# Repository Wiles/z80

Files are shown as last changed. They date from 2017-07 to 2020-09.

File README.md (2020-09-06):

# z80

## Purpose

Back in collage we had a real time operating systems course with targetted the Motorola 68000 CPU. It was a great course but our target platform was an emulator and not real hardware. This left a gap in my knoweldge of how things like chip selection and peripherals were handled by the hardware. Therefore I decided to design and build a barebones 8-bit computer and this is the results.

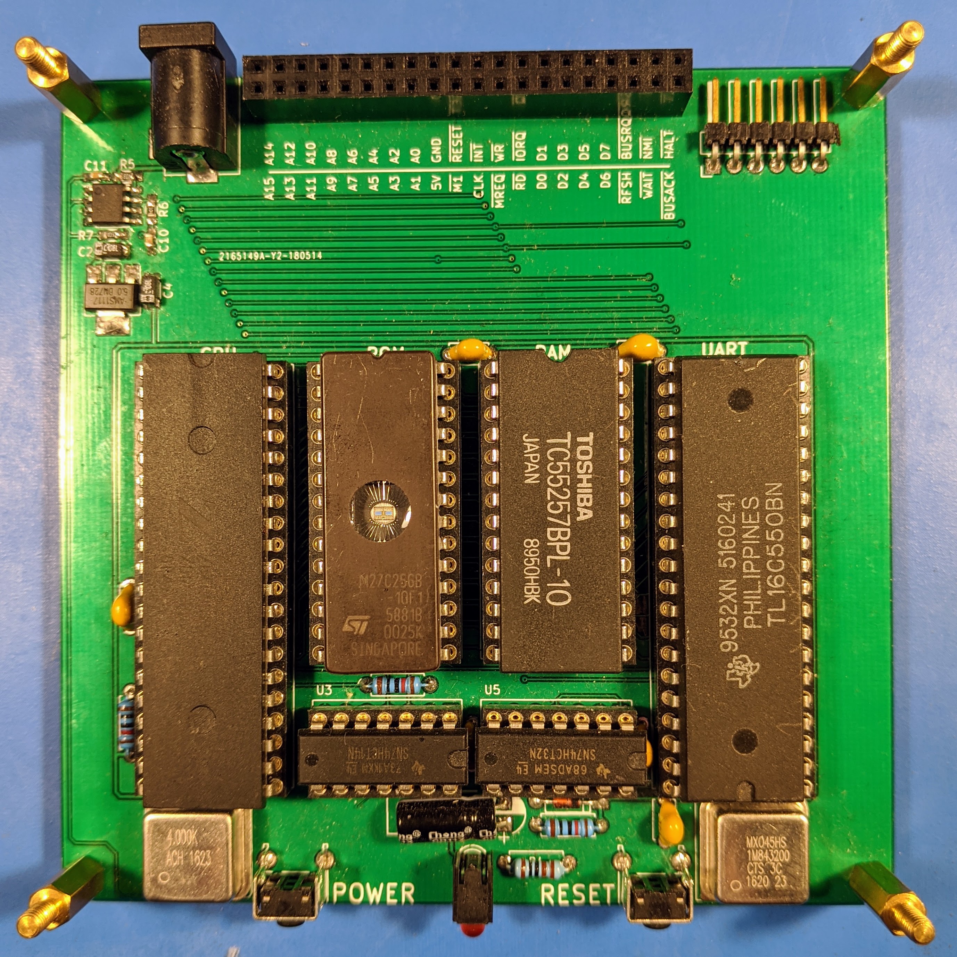
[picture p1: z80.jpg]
z80


## Memory Map

| Start | End | Description |
| --- | --- | --- |
| 0x0000 | 0x7FFF | ROM |
| 0x8000 | 0x0000 | RAM |

## IO Map

| Start | End | Description |
| --- | --- | --- |
| 0x80 | 0x87 | UART |

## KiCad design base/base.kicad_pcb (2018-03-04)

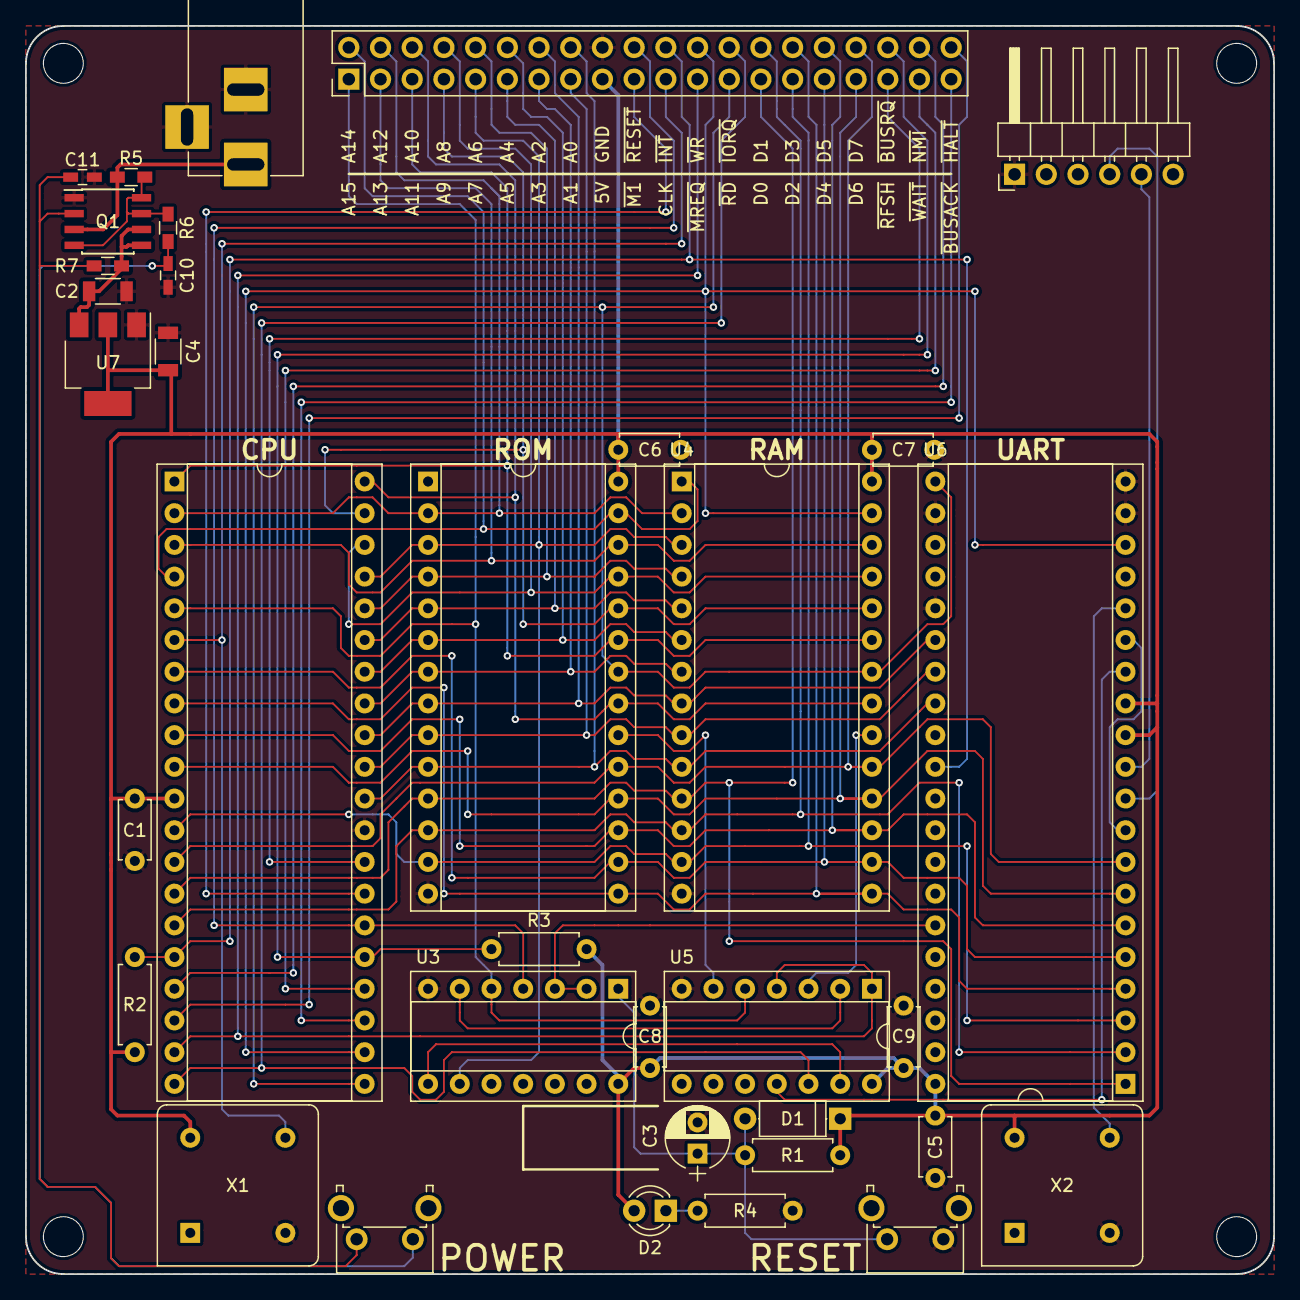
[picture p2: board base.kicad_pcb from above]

Board: 2 copper layers, 100.0 x 100.0 mm, 35 parts (0 on the bottom side), 57 nets.

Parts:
C1, C5, C6, C7, C8, C9: .1 uF; C_Disc_D4.7mm_W2.5mm_P5.00mm
C2, C4: 10 uF; C_1206
C3: 47 uF; CP_Radial_D5.0mm_P2.50mm
C10: 1 uF; C_0603_HandSoldering
C11: .1 uF; C_0603_HandSoldering
D1: 1N4148; D_A-405_P7.62mm_Horizontal
D2: LED; LED_D3.0mm
J1: FTDI; Pin_Header_Angled_1x06_Pitch2.54mm
J2: Barrel_Jack; BARREL_JACK
J3: CONN_01X40; Pin_Header_Straight_2x20_Pitch2.54mm
Q1: IRF7309IPBF; SOIC-8_3.9x4.9mm_Pitch1.27mm
R1, R2, R3: 10k; R_Axial_DIN0207_L6.3mm_D2.5mm_P7.62mm_Horizontal
R4: 1k; R_Axial_DIN0207_L6.3mm_D2.5mm_P7.62mm_Horizontal
R5, R7: 10k; R_0603_HandSoldering
R6: 100k; R_0603_HandSoldering
SW1: RESET; SW_Tactile_SPST_Angled_PTS645Vx31-2LFS
SW2: POWER; SW_Tactile_SPST_Angled_PTS645Vx31-2LFS
U1: Z80CPU; DIP-40_W15.24mm_Socket
U2: 27C256; DIP-28_W15.24mm_Socket
U3: 7404; DIP-14_W7.62mm_Socket
U4: 55257; DIP-28_W15.24mm_Socket
U5: 7432; DIP-14_W7.62mm_Socket
U6: 16550; DIP-40_W15.24mm_Socket
U7: AP1117-50; SOT-223-3Lead_TabPin2
X1: 4 MHz; Oscillator_DIP-8
X2: 1.8432 MHz; Oscillator_DIP-8

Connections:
+5V: C1.1, C4.1, C5.1, C6.1, C7.1, C8.1, C9.1, D1.1, D2.2, J3.17, R1.1, R2.2, R3.2, U1.11, U2.28, U3.14, U4.28, U5.14, U6.12, U6.13, U6.40, U7.2, X1.8, X2.8
+VDC: J2.1, Q1.3, R5.2
+VSW: C2.1, Q1.5, Q1.6, R7.1, U7.3
/A0: J3.16, U1.30, U2.10, U4.10, U6.28
/A1: J3.15, U1.31, U2.9, U4.9, U6.27
/A2: J3.14, U1.32, U2.8, U4.8, U6.26
/A3: J3.13, U1.33, U2.7, U4.7
/A4: J3.12, U1.34, U2.6, U4.6
/A5: J3.11, U1.35, U2.5, U4.5
/A6: J3.10, U1.36, U2.4, U4.4
/A7: J3.9, U1.37, U2.3, U3.9, U4.3
/A8: J3.8, U1.38, U2.25, U4.25
/A9: J3.7, U1.39, U2.24, U4.24
/A10: J3.6, U1.40, U2.21, U4.21
/A11: J3.5, U1.1, U2.23, U4.23
/A12: J3.4, U1.2, U2.2, U4.2
/A13: J3.3, U1.3, U2.26, U4.26
/A14: J3.2, U1.4, U2.27, U4.1
/A15: J3.1, U1.5, U3.5, U5.5
/D0: J3.27, U1.14, U2.11, U4.11, U6.1
/D1: J3.28, U1.15, U2.12, U4.12, U6.2
/D2: J3.29, U1.12, U2.13, U4.13, U6.3
/D3: J3.30, U1.8, U2.15, U4.15, U6.4
/D4: J3.31, U1.7, U2.16, U4.16, U6.5
/D5: J3.32, U1.9, U2.17, U4.17, U6.6
/D6: J3.33, U1.10, U2.18, U4.18, U6.7
/D7: J3.34, U1.13, U2.19, U4.19, U6.8
BUSACK: J3.39, U1.23
BUSRQ: J3.36, R3.1, U1.25
CLOCK: J3.21, U1.6, X1.5
GND: C1.2, C2.2, C3.2, C4.2, C5.2, C6.2, C7.2, C8.2, C9.2, C10.2, C11.2, J1.1, J2.2, J2.3, J3.18, Q1.1, R4.1, SW1.1, U1.29, U2.14, U3.7, U4.14, U5.7, U6.19, U6.20, U6.22, U6.25, U7.1, X1.4, X2.4
HALT: J3.40, U1.18
INT: J3.22, R2.1, U1.16, U6.30
IORQ: J3.26, U1.20, U5.12
M1: J3.19, U1.27
MREQ: J3.23, U1.19, U5.1, U5.4
NMI: J3.38, U1.17
unnamed: C3.1, D1.2, R1.2, SW1.2, U3.1
unnamed: C10.1, R6.2, SW2.1
unnamed: C11.1, Q1.2, R7.2, SW2.2
unnamed: D2.1, R4.2
unnamed: Q1.4, Q1.7, Q1.8, R5.1, R6.1
unnamed: U3.6, U5.2
unnamed: U3.8, U5.13
unnamed: U6.9, U6.15
unnamed: U6.16, X2.5
RAM_CE: U4.20, U5.3
RD: J3.25, U1.21, U2.22, U4.22, U6.21
RESET: U3.2, U3.3, U6.35
RFSH: J3.35, U1.28
ROM_CE: U2.20, U5.6
RX: J1.5, U6.11
TX: J1.4, U6.10
UART_CE: U5.11, U6.14
WAIT: J3.37, U1.24
WR: J3.24, U1.22, U4.27, U6.18
~RESET~: J3.20, U1.26, U3.4

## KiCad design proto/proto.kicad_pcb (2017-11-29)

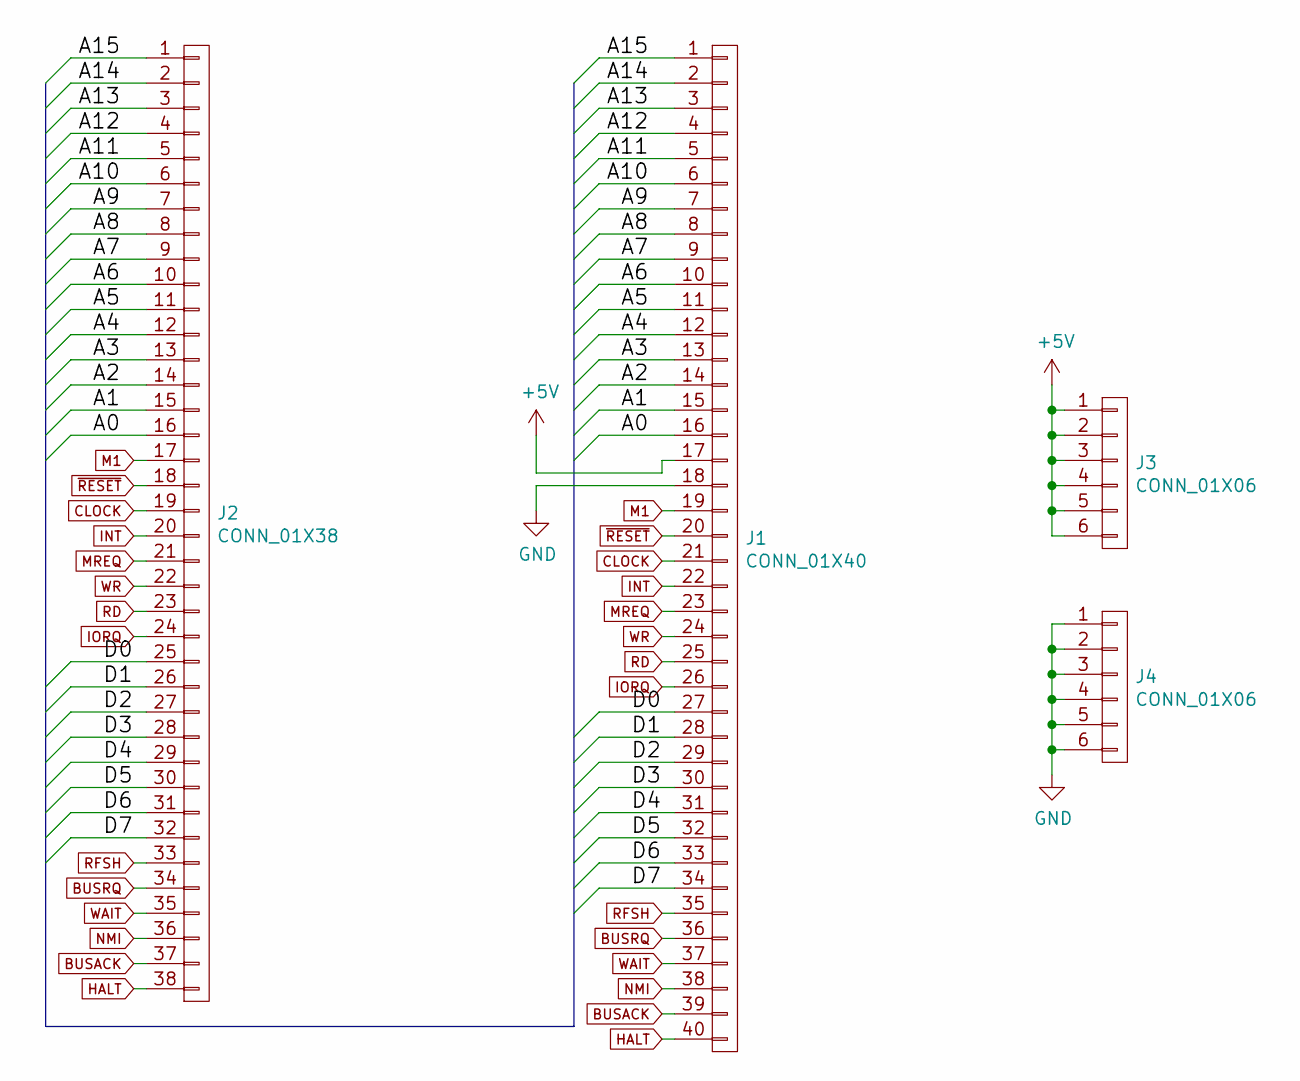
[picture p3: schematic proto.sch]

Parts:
J1: CONN_01X40; Pin_Header_Straight_2x20_Pitch2.54mm
J2: CONN_01X38; Pin_Header_Straight_1x38_Pitch2.54mm
J3, J4: CONN_01X06; Pin_Header_Straight_1x06_Pitch2.54mm

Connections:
+5V: J1.17, J3.1, J3.2, J3.3, J3.4, J3.5, J3.6
/A0: J1.16, J2.16
/A1: J1.15, J2.15
/A2: J1.14, J2.14
/A3: J1.13, J2.13
/A4: J1.12, J2.12
/A5: J1.11, J2.11
/A6: J1.10, J2.10
/A7: J1.9, J2.9
/A8: J1.8, J2.8
/A9: J1.7, J2.7
/A10: J1.6, J2.6
/A11: J1.5, J2.5
/A12: J1.4, J2.4
/A13: J1.3, J2.3
/A14: J1.2, J2.2
/A15: J1.1, J2.1
/D0: J1.27, J2.25
/D1: J1.28, J2.26
/D2: J1.29, J2.27
/D3: J1.30, J2.28
/D4: J1.31, J2.29
/D5: J1.32, J2.30
/D6: J1.33, J2.31
/D7: J1.34, J2.32
BUSACK: J1.39, J2.37
BUSRQ: J1.36, J2.34
CLOCK: J1.21, J2.19
GND: J1.18, J4.1, J4.2, J4.3, J4.4, J4.5, J4.6
HALT: J1.40, J2.38
INT: J1.22, J2.20
IORQ: J1.26, J2.24
M1: J1.19, J2.17
MREQ: J1.23, J2.21
NMI: J1.38, J2.36
RD: J1.25, J2.23
RFSH: J1.35, J2.33
WAIT: J1.37, J2.35
WR: J1.24, J2.22
~RESET~: J1.20, J2.18

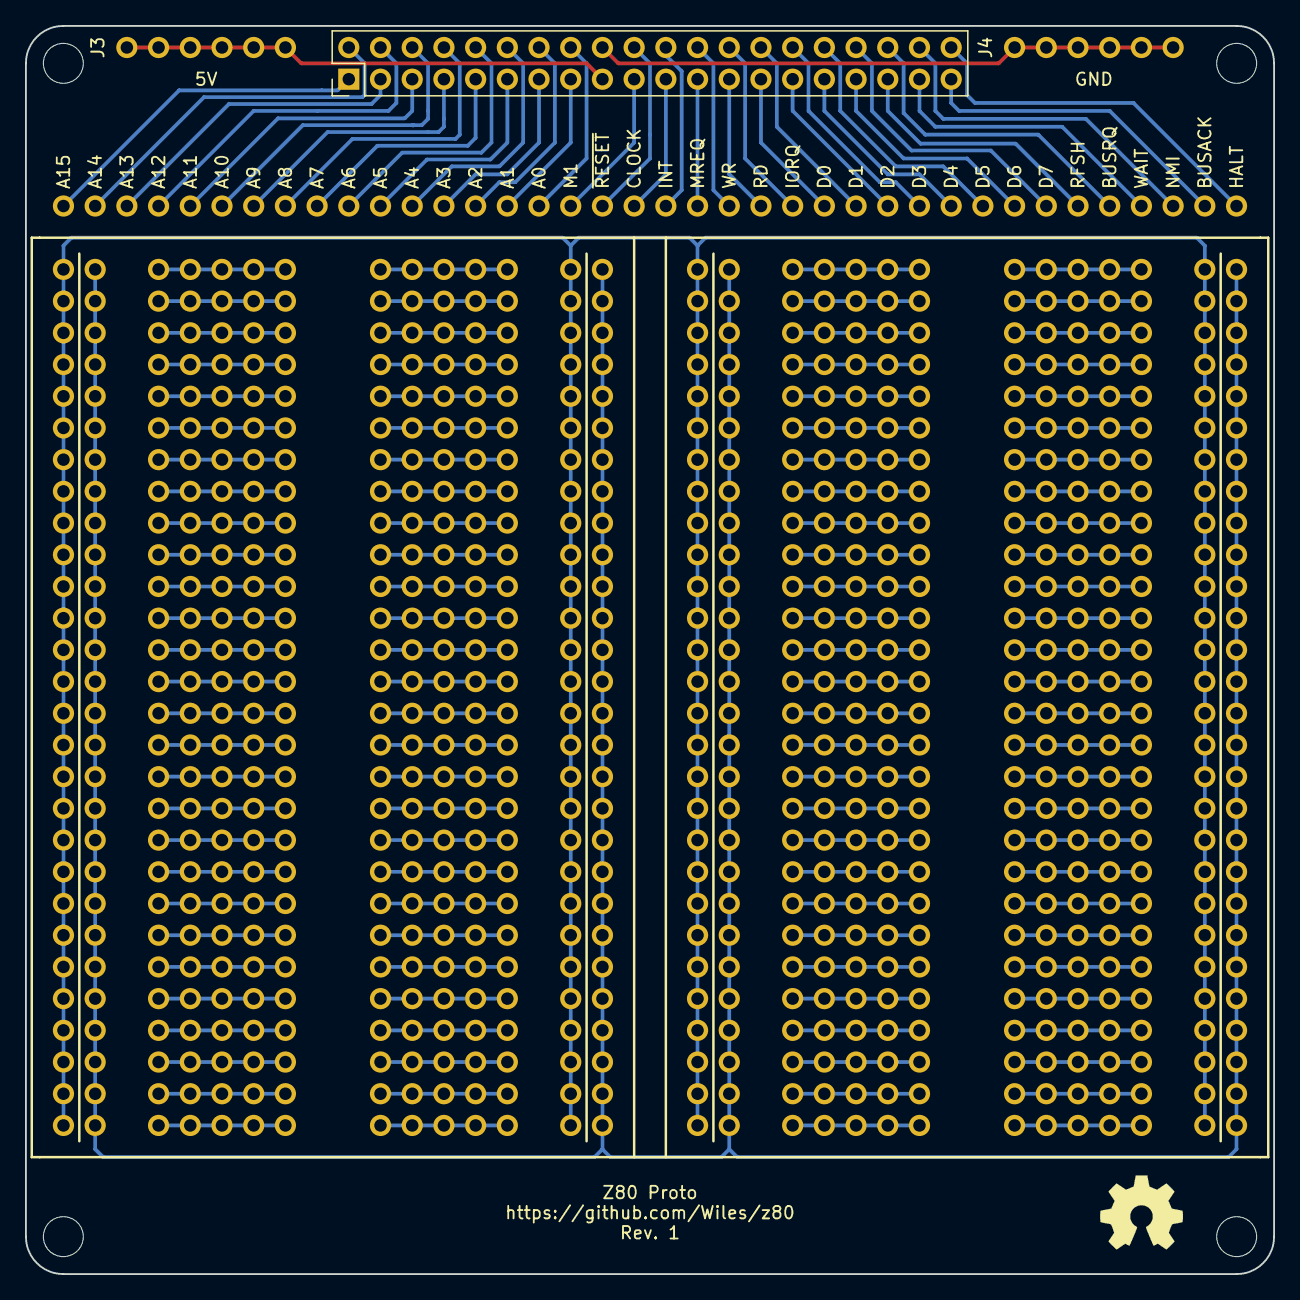
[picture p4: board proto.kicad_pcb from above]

Board: 2 copper layers, 100.0 x 100.0 mm, 4 parts (0 on the bottom side), 40 nets.

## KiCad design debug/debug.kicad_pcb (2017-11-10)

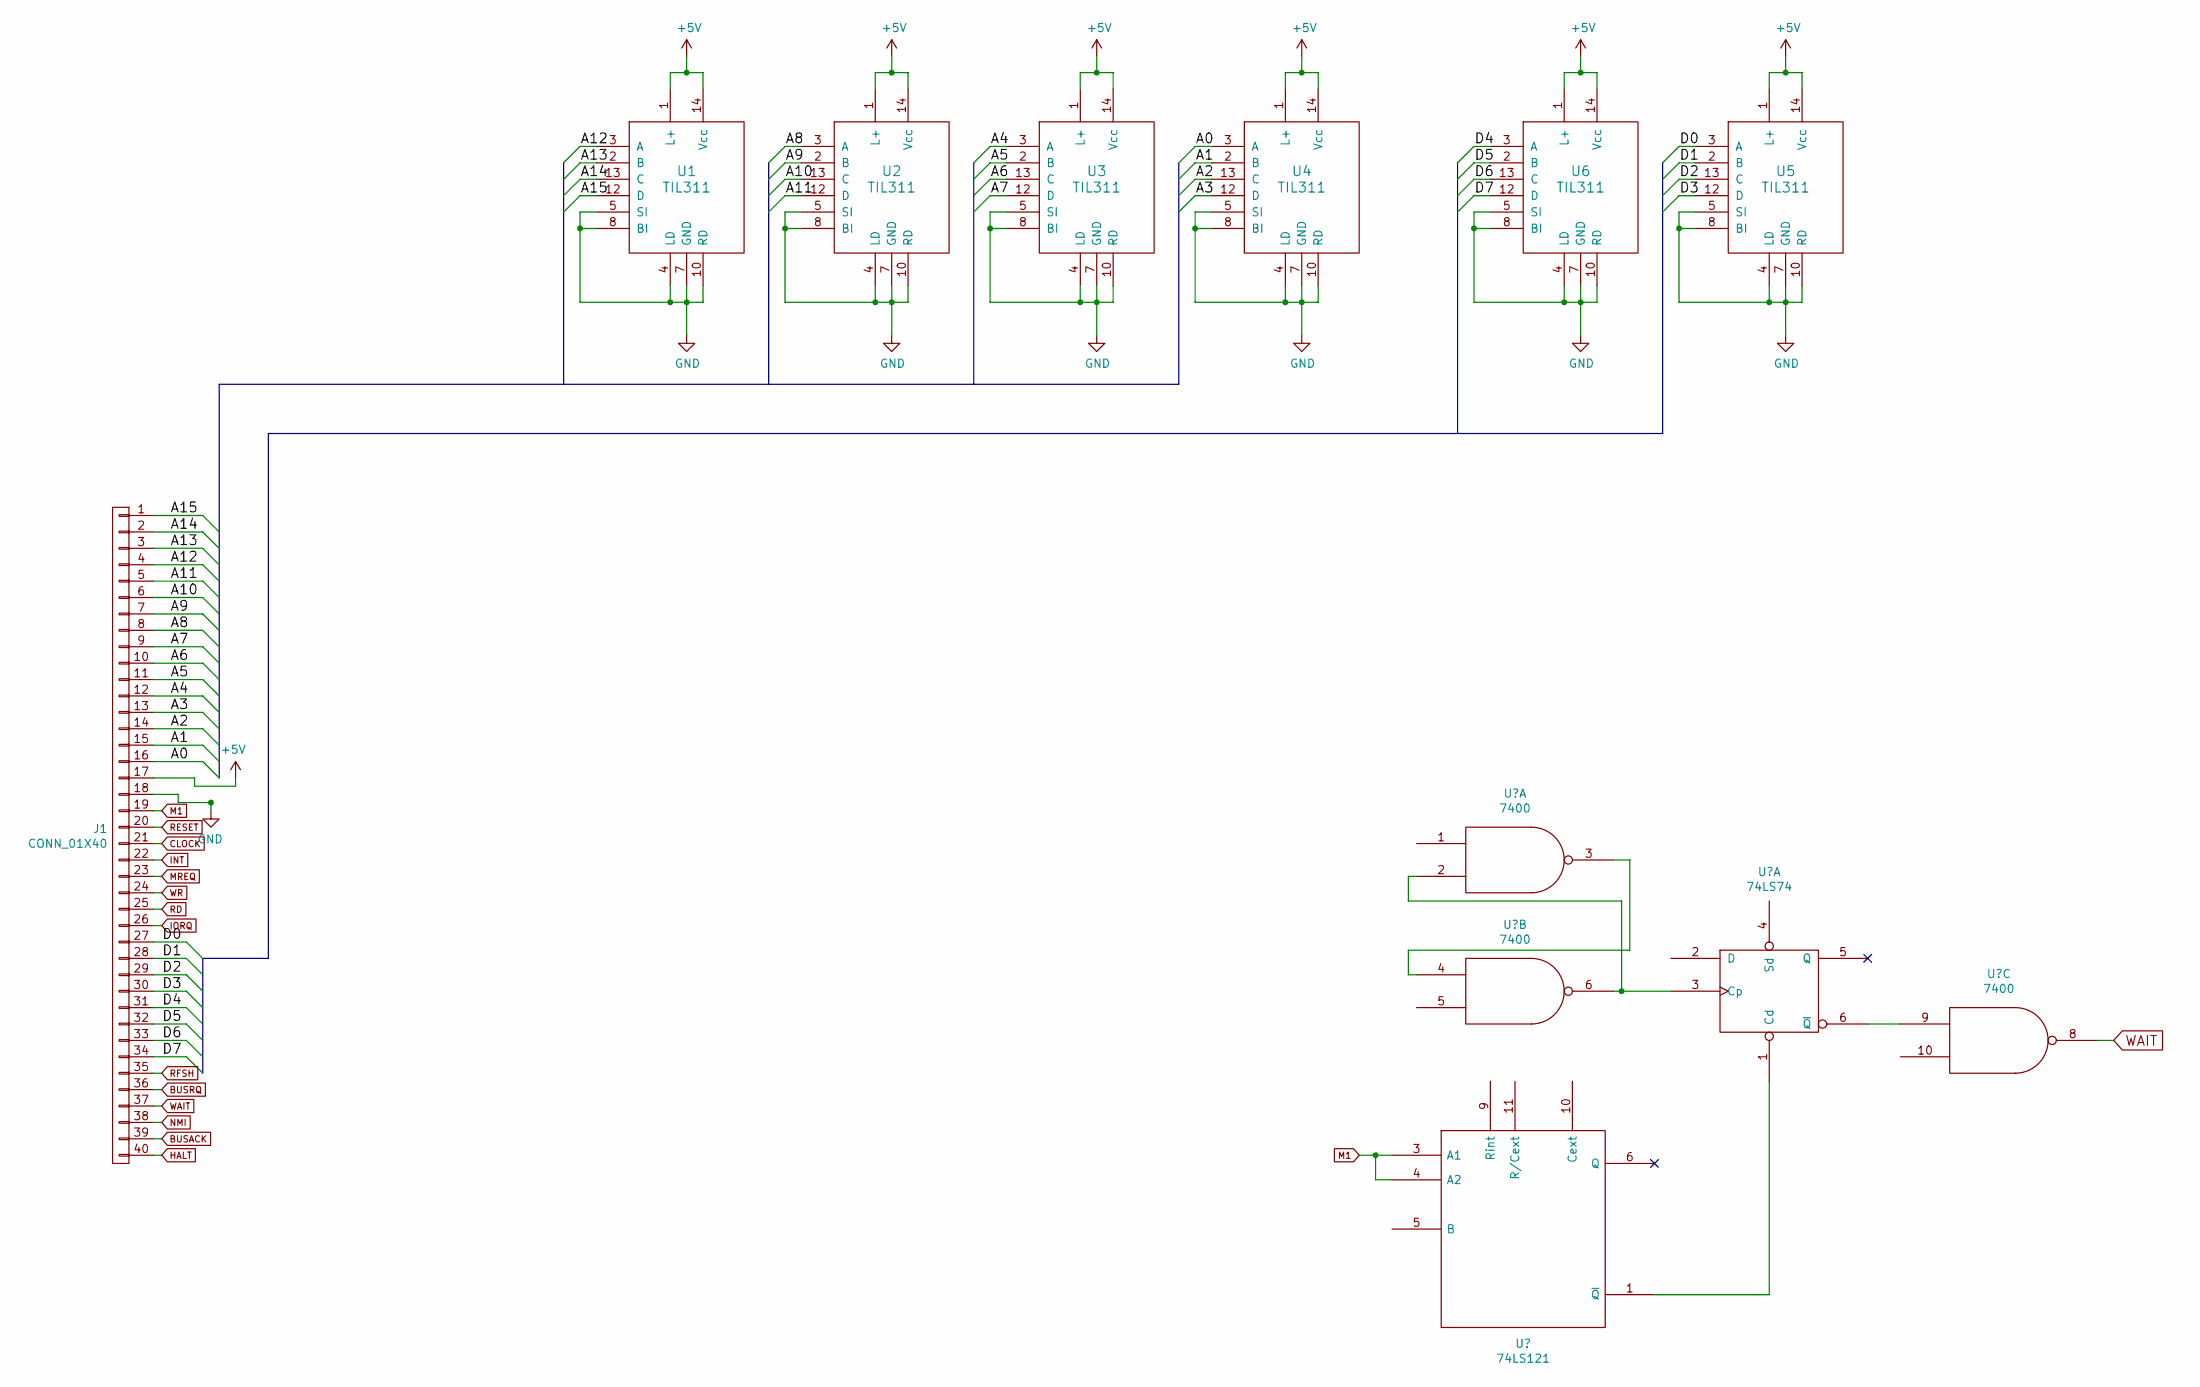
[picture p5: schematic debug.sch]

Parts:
J1: CONN_01X40; Pin_Header_Straight_2x20_Pitch2.54mm
U1, U2, U3, U4, U5, U6: TIL311; DIP-14_W7.62mm_Socket

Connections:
+5V: J1.17, U1.1 (L+), U1.14 (Vcc), U2.1 (L+), U2.14 (Vcc), U3.1 (L+), U3.14 (Vcc), U4.1 (L+), U4.14 (Vcc), U5.1 (L+), U5.14 (Vcc), U6.1 (L+), U6.14 (Vcc)
/A0: J1.16, U4.3 (A)
/A1: J1.15, U4.2 (B)
/A2: J1.14, U4.13 (C)
/A3: J1.13, U4.12 (D)
/A4: J1.12, U3.3 (A)
/A5: J1.11, U3.2 (B)
/A6: J1.10, U3.13 (C)
/A7: J1.9, U3.12 (D)
/A8: J1.8, U2.3 (A)
/A9: J1.7, U2.2 (B)
/A10: J1.6, U2.13 (C)
/A11: J1.5, U2.12 (D)
/A12: J1.4, U1.3 (A)
/A13: J1.3, U1.2 (B)
/A14: J1.2, U1.13 (C)
/A15: J1.1, U1.12 (D)
/D0: J1.27, U5.3 (A)
/D1: J1.28, U5.2 (B)
/D2: J1.29, U5.13 (C)
/D3: J1.30, U5.12 (D)
/D4: J1.31, U6.3 (A)
/D5: J1.32, U6.2 (B)
/D6: J1.33, U6.13 (C)
/D7: J1.34, U6.12 (D)
BUSACK: J1.39
BUSRQ: J1.36
CLOCK: J1.21
GND: J1.18, U1.4 (LD), U1.5 (SI), U1.7 (GND), U1.8 (BI), U1.10 (RD), U2.4 (LD), U2.5 (SI), U2.7 (GND), U2.8 (BI), U2.10 (RD), U3.4 (LD), U3.5 (SI), U3.7 (GND), U3.8 (BI), U3.10 (RD), U4.4 (LD), U4.5 (SI), U4.7 (GND), U4.8 (BI), U4.10 (RD), U5.4 (LD), U5.5 (SI), U5.7 (GND), U5.8 (BI), U5.10 (RD), U6.4 (LD), U6.5 (SI), U6.7 (GND), U6.8 (BI), U6.10 (RD)
HALT: J1.40
INT: J1.22
IORQ: J1.26
M1: J1.19
MREQ: J1.23
NMI: J1.38
RD: J1.25
RESET: J1.20
RFSH: J1.35
WAIT: J1.37
WR: J1.24

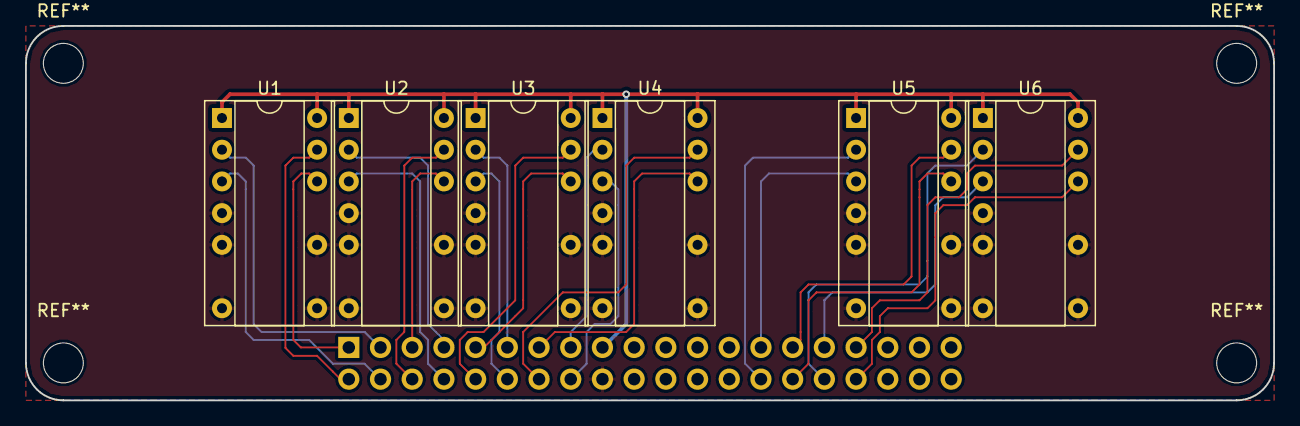
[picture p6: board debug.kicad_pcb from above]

Board: 2 copper layers, 100.0 x 30.0 mm, 7 parts (1 on the bottom side), 26 nets.

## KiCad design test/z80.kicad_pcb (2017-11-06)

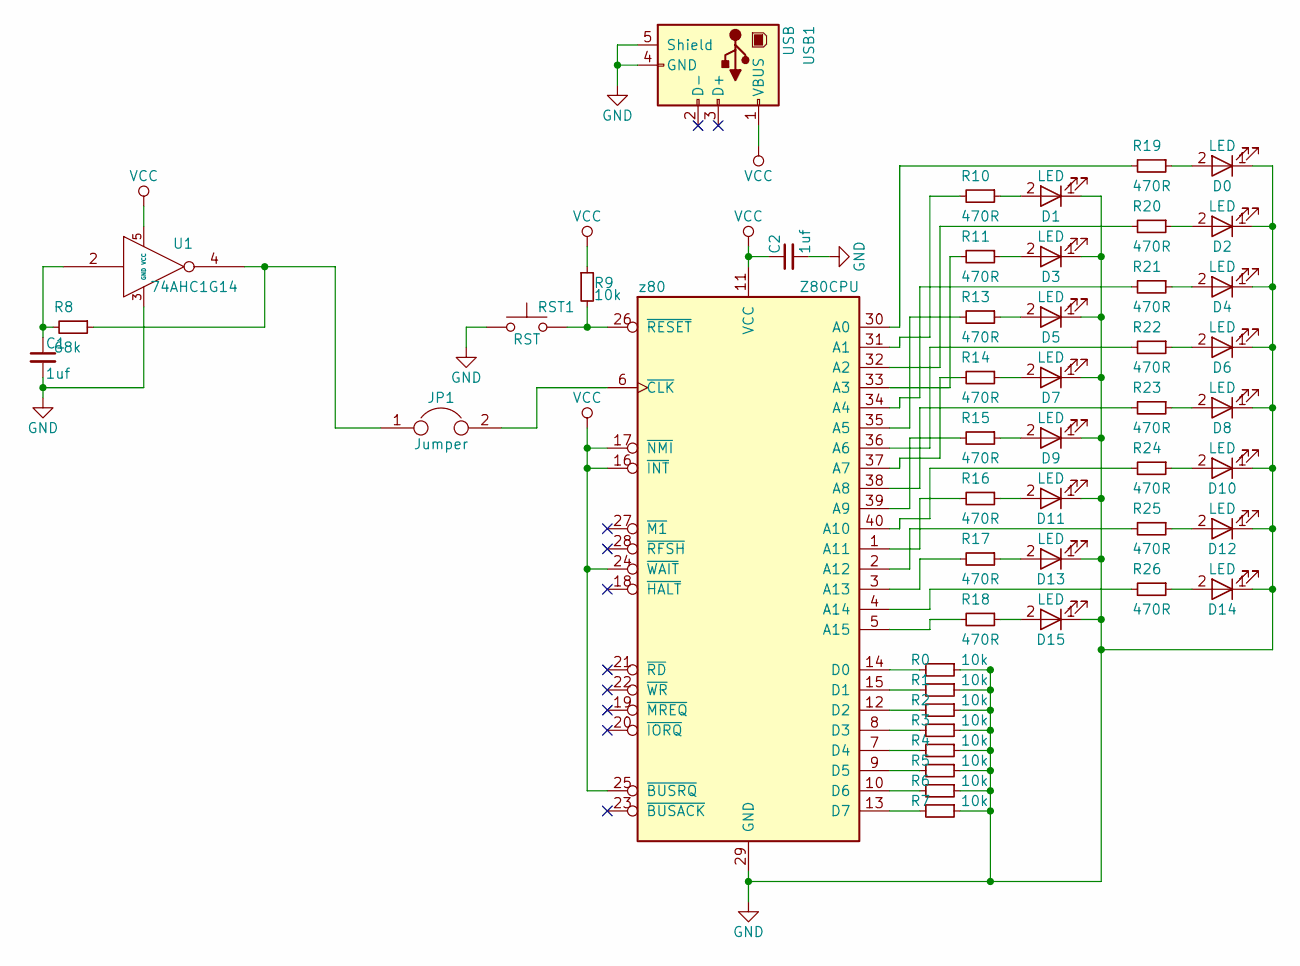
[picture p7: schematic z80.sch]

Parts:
C1: 1uf; C_Disc_D5.1mm_W3.2mm_P5.00mm
C2: 1uf; C_0805_HandSoldering
D0, D1, D2, D3, D4, D5, D6, D7, D8, D9, D10, D11, D12, D13, D14, D15: LED; LED_0805
JP1: Jumper; Pin_Header_Straight_1x02_Pitch2.54mm
R0, R1, R2, R3, R4, R5, R6, R7, R9: 10k; R_0805_HandSoldering
R8: 68k; R_0805_HandSoldering
R10, R11, R13, R14, R15, R16, R17, R18, R19, R20, R21, R22, R23, R24, R25, R26: 470R; R_0805_HandSoldering
RST1: RST; SW_SPST_TL3342
U1: 74AHC1G14; SOT-353_SC-70-5_Handsoldering
USB1: USB; USB_Micro-B_Molex_47346-0001
z80: Z80CPU; 40tex-Ell600

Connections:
GND: C1.2, C2.2, D0.1 (K), D1.1 (K), D2.1 (K), D3.1 (K), D4.1 (K), D5.1 (K), D6.1 (K), D7.1 (K), D8.1 (K), D9.1 (K), D10.1 (K), D11.1 (K), D12.1 (K), D13.1 (K), D14.1 (K), D15.1 (K), R0.1, R1.1, R2.1, R3.1, R4.1, R5.1, R6.1, R7.1, RST1.1, U1.3 (GND), USB1.4 (GND), USB1.5 (Shield), z80.29 (GND)
unnamed: C1.1, R8.2, U1.2
unnamed: D0.2 (A), R19.1
unnamed: D1.2 (A), R10.1
unnamed: D2.2 (A), R20.1
unnamed: D3.2 (A), R11.1
unnamed: D4.2 (A), R21.1
unnamed: D5.2 (A), R13.1
unnamed: D6.2 (A), R22.1
unnamed: D7.2 (A), R14.1
unnamed: D8.2 (A), R23.1
unnamed: D9.2 (A), R15.1
unnamed: D10.2 (A), R24.1
unnamed: D11.2 (A), R16.1
unnamed: D12.2 (A), R25.1
unnamed: D13.2 (A), R17.1
unnamed: D14.2 (A), R26.1
unnamed: D15.2 (A), R18.1
unnamed: JP1.1, R8.1, U1.4
unnamed: JP1.2, z80.6 (~CLK~)
unnamed: R0.2, z80.14 (D0)
unnamed: R1.2, z80.15 (D1)
unnamed: R2.2, z80.12 (D2)
unnamed: R3.2, z80.8 (D3)
unnamed: R4.2, z80.7 (D4)
unnamed: R5.2, z80.9 (D5)
unnamed: R6.2, z80.10 (D6)
unnamed: R7.2, z80.13 (D7)
unnamed: R9.2, RST1.2, z80.26 (~RESET~)
unnamed: R10.2, z80.31 (A1)
unnamed: R11.2, z80.33 (A3)
unnamed: R13.2, z80.35 (A5)
unnamed: R14.2, z80.37 (A7)
unnamed: R15.2, z80.39 (A9)
unnamed: R16.2, z80.1 (A11)
unnamed: R17.2, z80.3 (A13)
unnamed: R18.2, z80.5 (A15)
unnamed: R19.2, z80.30 (A0)
unnamed: R20.2, z80.32 (A2)
unnamed: R21.2, z80.34 (A4)
unnamed: R22.2, z80.36 (A6)
unnamed: R23.2, z80.38 (A8)
unnamed: R24.2, z80.40 (A10)
unnamed: R25.2, z80.2 (A12)
unnamed: R26.2, z80.4 (A14)
VCC: C2.1, R9.1, U1.5 (VCC), USB1.1 (VBUS), z80.11 (VCC), z80.16 (~INT~), z80.17 (~NMI~), z80.24 (~WAIT~), z80.25 (~BUSRQ~)

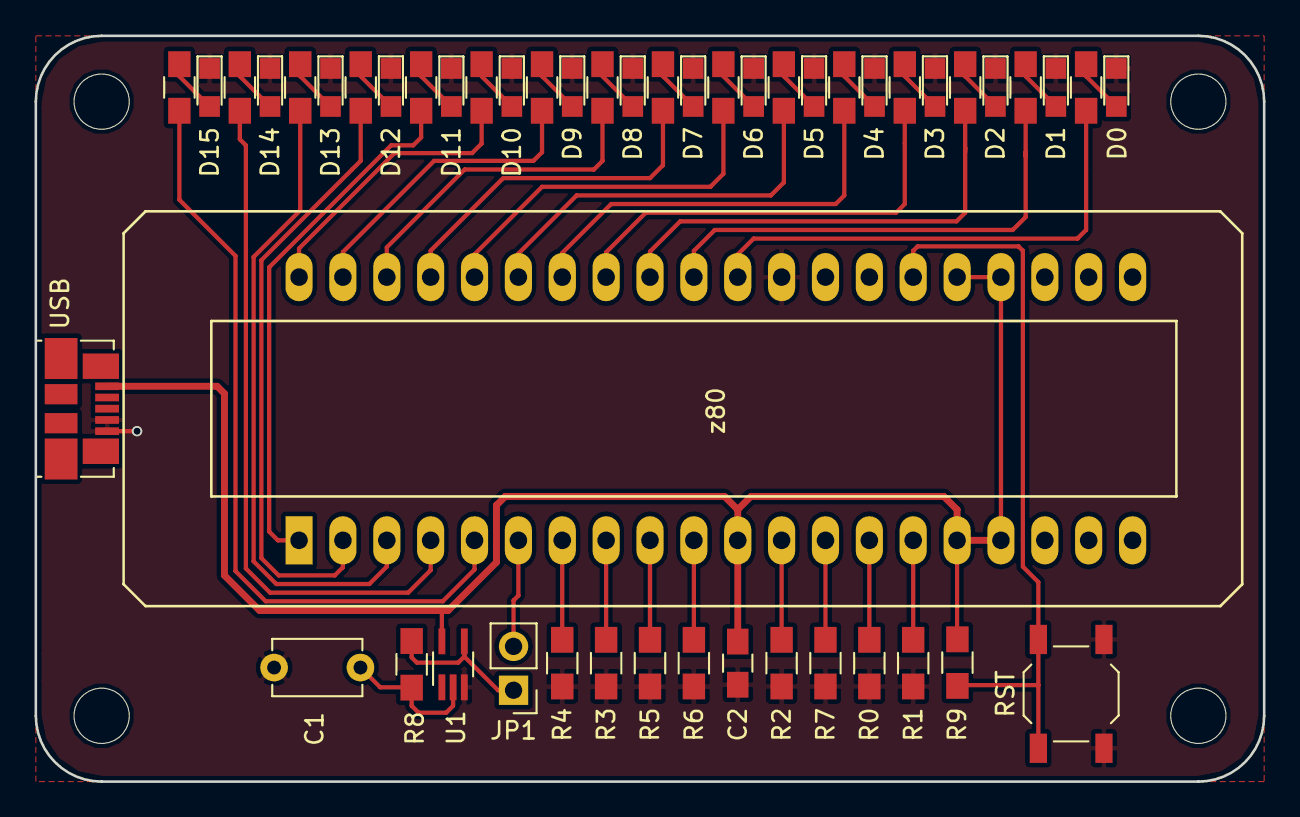
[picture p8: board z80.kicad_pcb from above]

Board: 2 copper layers, 71.1 x 43.2 mm, 49 parts (0 on the bottom side), 46 nets.

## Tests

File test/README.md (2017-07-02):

Based on the test circuit provided at http://www.z80.info/z80test0.htm.

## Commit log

2017-06-18 Revision 1 of z80 CPU test PCB
    [z80.kicad_pcb, z80.sch]
2017-06-18 Ignore gerber files
2017-06-29 Test board revision 2
    - Replaced quad NAND gate with single NOT gate
    - Broke out remaining address lines to LEDs
    [z80.kicad_pcb, z80.sch]
2017-06-29 Increase VCC track width
    [z80.kicad_pcb]
2017-06-29 Moved reset button label
    [z80.kicad_pcb]
2017-06-29 Renumber data pulldowns and address LEDs to match bits
    [_saved_z80.sch, z80.kicad_pcb]
2017-07-02 Added jumper on clock signal and replaced C1 with THT footprint.
    [_saved_z80.sch, z80.kicad_pcb, z80.sch]
2017-07-12 Replaced clock charge cap footprint with ceramic cap
    [z80.kicad_pcb]
2017-07-13 Start of base board design
    [base.kicad_pcb, base.sch]
2017-07-17 Layout work
    [base.kicad_pcb, base.sch]
2017-07-17 Replaced SMD passives with THT
    [base.kicad_pcb, base.sch]
2017-08-07 Further layout work
    [base.kicad_pcb, base.sch]
2017-10-29 Added SVG exports of current schematics
2017-10-29 Added RC2014 header to schematic
    [base.sch]
2017-10-30 Started layout of RC2014 header
    [base.kicad_pcb]
2017-11-05 Finished board layout
    [base.kicad_pcb]
2017-11-05 Changed FTDI and CLK_JMP footprint
    [base.kicad_pcb, base.sch]
2017-11-05 Fixed silkscreen
    [base.kicad_pcb]
2017-11-05 Broke out remaining z80 pins
    [base.sch]
2017-11-05 Board layout for remaining pins
    [base.kicad_pcb, base.sch]
2017-11-06 Clean up traces
    [base.kicad_pcb, base.sch]
2017-11-06 Fixed board cutout
    [base.kicad_pcb, base.sch]
2017-11-06 Replaced main header with 2x20
    [base.kicad_pcb, base.sch]
2017-11-06 Added barrel jack
    [base.kicad_pcb, base.sch]
2017-11-06 Minor layout changes
    [base.kicad_pcb, z80.kicad_pcb, z80.sch]
2017-11-06 Added regulation to input voltage
    [base.kicad_pcb, base.sch]
2017-11-06 Fixed fill zones
    [base.kicad_pcb]
2017-11-07 Change reset switch to right angle
    [_saved_base.sch, base.kicad_pcb]
2017-11-07 Moved voltage regulator
    [base.kicad_pcb]
2017-11-07 Fixed capacitor sizes
    [_saved_base.sch, base.kicad_pcb, base.sch]
2017-11-07 Readded mounting holes
    [base.kicad_pcb]
2017-11-07 Redid power trace
    [base.kicad_pcb]
2017-11-08 Increased size of voltage regulator
    [base.kicad_pcb, base.sch]
2017-11-08 Moved FTDI port
    [base.kicad_pcb]
2017-11-08 Rev 1
    [base.kicad_pcb]
2017-11-09 Start of debug board
    [debug.kicad_pcb, debug.sch]
2017-11-10 Display layout on debug board
    [debug.kicad_pcb, debug.sch]
2017-11-17 Fixed decoupling caps
    [base.kicad_pcb, base.sch]
2017-11-18 Clean up schematic and added more decoupling
    [base.kicad_pcb, base.sch]
2017-11-19 Cleaned up layout
    [base.kicad_pcb, base.sch]
2017-11-29 First revision of prototyping board
    [proto.kicad_pcb, proto.sch]
2018-02-19 Added pullups to busrq and int pins
    [base.kicad_pcb, base.sch]
2018-03-04 Added pinout to silkscreen
    [base.kicad_pcb]
2018-03-04 Added power indicator light and changed FTDI footprint
    [base-2018-03-04-11-00-15.sch, base.kicad_pcb]
2018-03-04 Added soft power button
    [base.kicad_pcb, base.sch]
2018-03-04 Fixed header pinout on back silkscreen
    [base.kicad_pcb]
